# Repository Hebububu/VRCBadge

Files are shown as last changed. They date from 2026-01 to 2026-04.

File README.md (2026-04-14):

<div align="center">

# VRCBadge

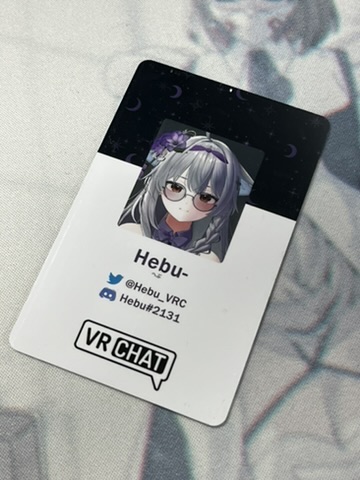
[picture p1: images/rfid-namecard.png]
RFID Namecard


I made RFID namecard before (for friends and myself)<br>
and you know, all VRC players change avatar quite often.

After making those namecards 3 times (dumb),<br>
I decided to make a digital badge for myself. (simple + fun toy project!)

It's gonna be a wearable digital badge powered by ESP32-S3<br>
Namecard looking UI (Yes, changeable image ofc)<br>
editable profile information (twitter, discord etc..), and future RFID door key emulation.

This project is inspired by Github Conference Badge video, posted by Wes Bos. [Ref Video](https://youtu.be/_jPm_zN95FE?si=vHjaHDR8lpRF7iKP)

### Working Prototype

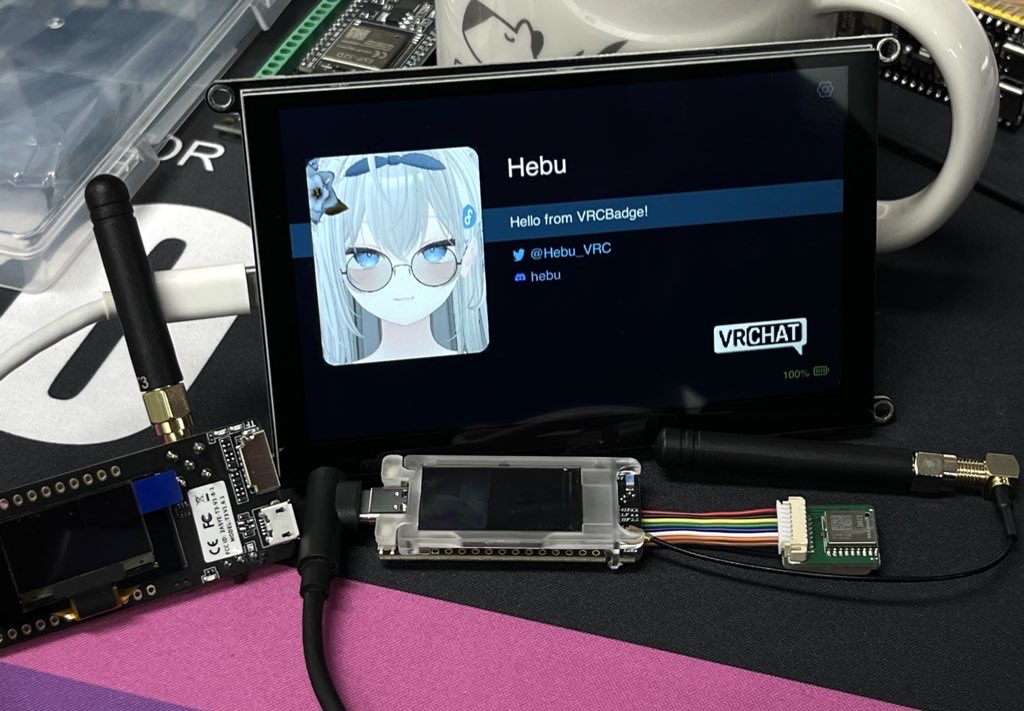
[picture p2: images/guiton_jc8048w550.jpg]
Badge running on Guition JC8048W550


Badge UI running on a Guition JC8048W550 dev board (ESP32-S3 + 4.8" RGB parallel LCD with capacitive touch). Built with [Slint](https://slint.dev).

### Enclosure (WIP)

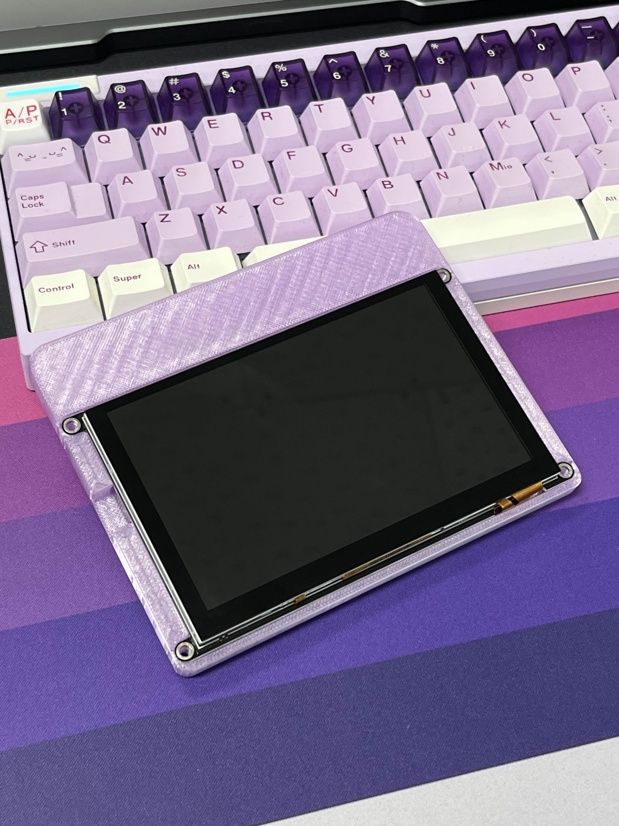
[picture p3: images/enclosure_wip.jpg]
Enclosure WIP

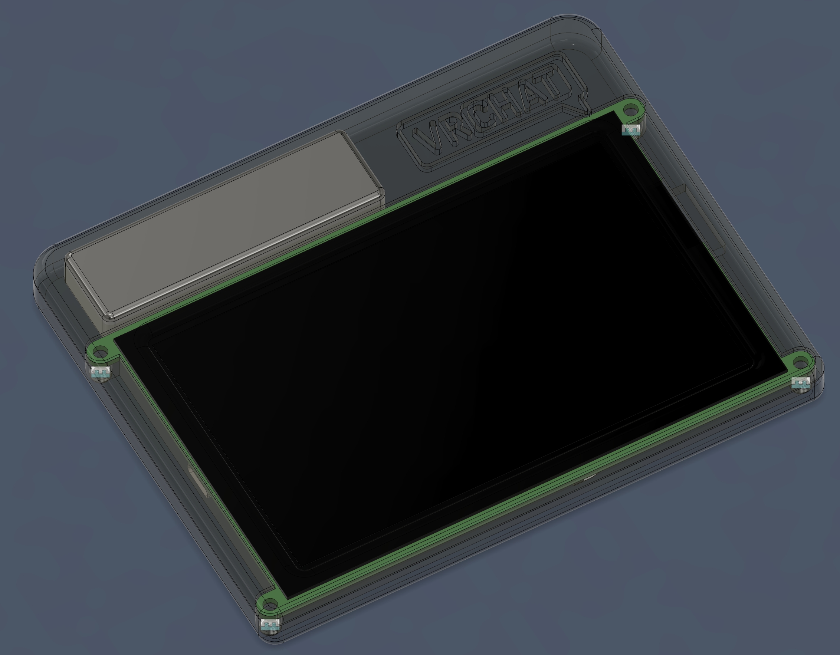
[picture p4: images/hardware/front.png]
Enclosure front render

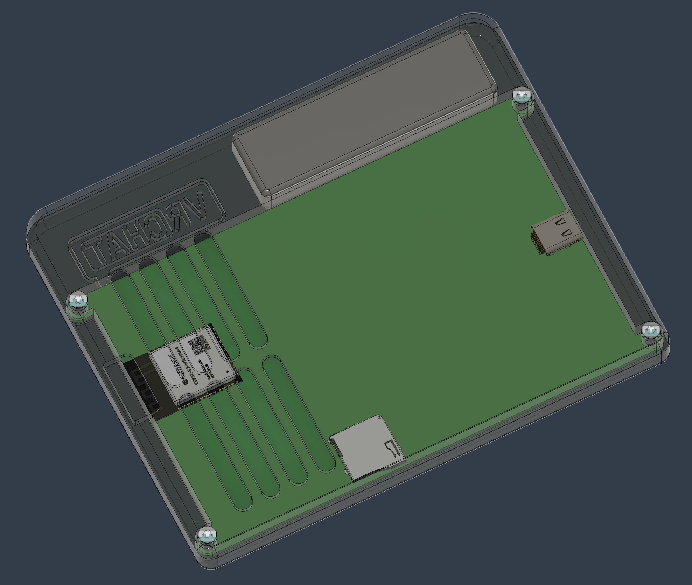
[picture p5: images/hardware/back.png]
Enclosure back render


Enclosure drawn with Autodesk Fusion 360.

### Schematic (Future)

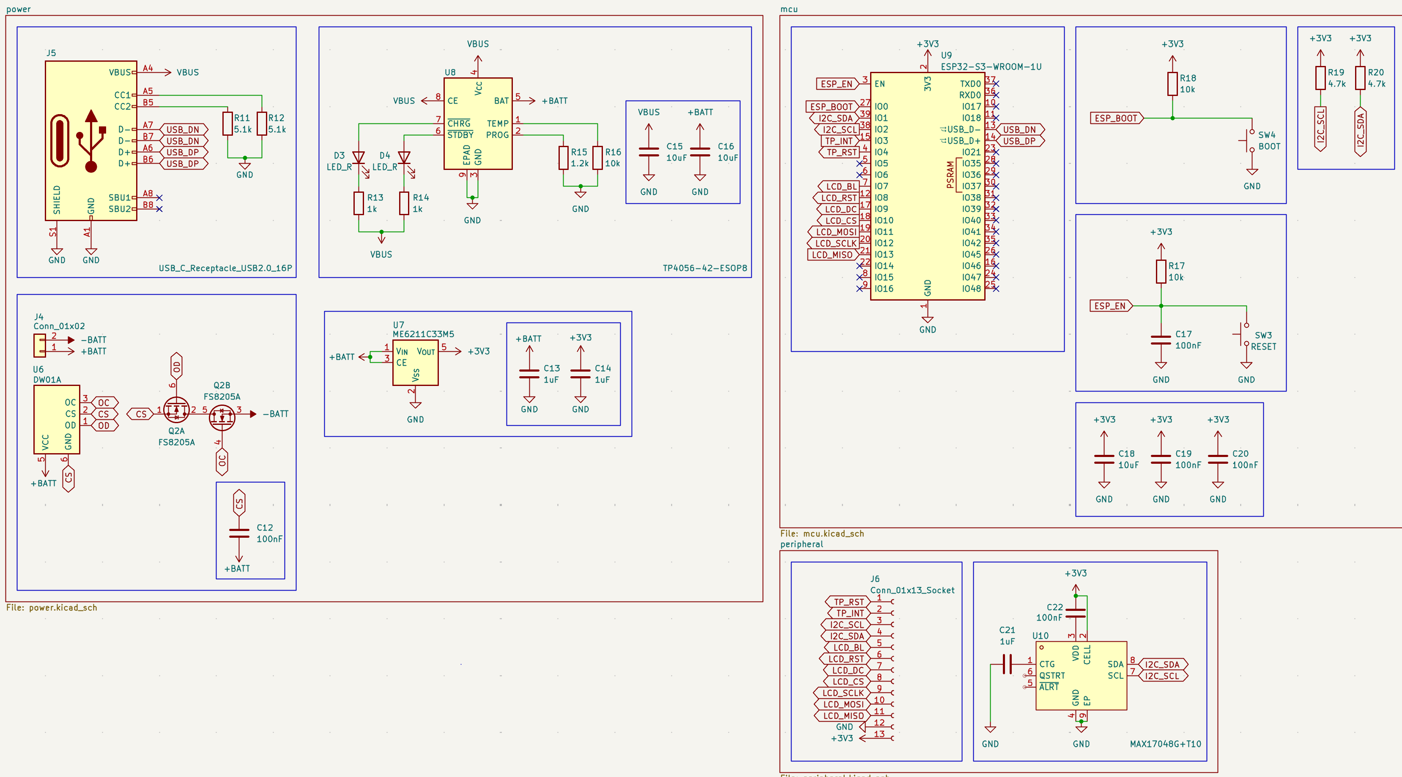
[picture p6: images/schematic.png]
Schematic


Custom 2-layer PCB designed for JLCPCB fabrication.
USB-C input with TP4056 LiPo charging, DW01A+FS8205A battery protection, and ME6211 3.3V LDO.
ESP32-S3-WROOM-1U drives a 3.5" SPI LCD with capacitive touch, while a MAX17048 fuel gauge tracks battery level over I2C.

</div>

## Documentation

See [/docs](./docs/README.md) for full documentation:

- [Hardware](./docs/hardware/) - ESP32-S3, custom PCB, display, BOM
- [Software](./docs/software/) - Architecture, API
- [RFID](./docs/rfid/) - Technical guide (future phase)

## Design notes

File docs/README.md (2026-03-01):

# Digital Conference Badge Documentation

A wearable digital badge with dynamic display, changeable avatar, and future RFID door key emulation.

## Documentation

### [Hardware](./hardware/)
- [Overview](./hardware/overview.md) - ESP32-S3 platform, Waveshare 3.5" display, PCB design, GPIO mapping, BOM
- [PCB Layout](./hardware/pcb.md) - Board dimensions, mounting holes, component placement

### [Software](./software/)
- [Architecture](./software/architecture.md) - System architecture, tech stack, data flow
- [API](./software/api.md) - HTTP endpoints documentation

### [RFID](./rfid/)
- [Technical Guide](./rfid/technical-guide.md) - RFID frequencies, reader vs emulator, Chameleon Tiny

## Resources

- [Slint Documentation](https://slint.dev/docs)
- [esp-idf-svc (Rust)](https://github.com/esp-rs/esp-idf-svc)
- [ESP32-S3 Datasheet](https://www.espressif.com/sites/default/files/documentation/esp32-s3_datasheet_en.pdf)
- [ESP-IDF Programming Guide](https://docs.espressif.com/projects/esp-idf/en/stable/esp32s3/)
- [esp-idf-hal (Rust)](https://github.com/esp-rs/esp-idf-hal)
- [Waveshare 3.5" RPi LCD (F)](https://www.waveshare.com/wiki/3.5inch_RPi_LCD_(F))
- [EasyEDA PCB Design](https://easyeda.com)
- [JLCPCB Fabrication](https://jlcpcb.com)
- [Chameleon Tiny Wiki](https://github.com/RfidResearchGroup/ChameleonUltra)

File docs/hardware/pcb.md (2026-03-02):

# PCB Layout

## Board Specification

- Width: 105mm
- Height: 80mm
- Corner radius: 2mm
- Mounting holes: 2mm diameter, one at each corner, 3.5mm from each edge

## Display Module Dimensions

Measurements from Waveshare 3.5" RPi LCD (F) specsheet.

### Panel Dimensions (front view, landscape orientation)

| Dimension | Value | Notes |
|---|---|---|
| Lens (outer) width | 92.44 +/- 0.20 mm | Glass/lens edge to edge |
| Lens (outer) height | 61.00 +/- 0.20 mm | Glass/lens edge to edge |
| Touch active area width | 73.84 +/- 0.10 mm | Usable touch/display region |
| Touch active area height | 49.36 +/- 0.10 mm | Usable touch/display region |
| Bezel left/right | 9.30 mm | Lens edge to active area |
| Bezel top/bottom | 5.82 mm | Lens edge to active area |

### PCB Dimensions (back view)

| Dimension | Value | Notes |
|---|---|---|
| PCB width | 56.00 mm | Back PCB behind the lens |
| PCB component area | 49.00 mm | Active component region |
| PCB left edge offset | 2.50 mm | From lens edge to PCB edge |
| PCB right edge offset | 3.50 mm | From lens edge to PCB edge |
| Connector row height | 3.46 mm | GH1.25 13-pin connector area |
| Mounting hole pattern | M2.50 | 4 holes on back PCB |
| Mounting hole spacing (vertical) | 27.73 mm | Between hole centers |
| Connector offset from edge | 2.31 mm | Horizontal offset |
| Component spacing | 2.55 mm | Between connector groups |

### Stack Height (side profile)

| Layer | Thickness | Notes |
|---|---|---|
| Touch panel + LCD | 3.95 mm | Glass + LCD panel combined |
| Air gap / clearance | 0.80 mm | Between LCD and back PCB |
| Back PCB + components | 6.60 mm | PCB with tallest component |
| **Total stack** | **~14.60 mm** | Front glass to back component tip |

### FPC Cable

| Dimension | Value | Notes |
|---|---|---|
| FPC exit direction | Bottom edge | In portrait orientation |
| FPC extension length | ~24.00 mm | Flexible cable extends from panel |
| FPC width | ~15.28 mm | Approximate |

## Orientation

All directions described as viewed from the front (LCD-facing) side.
Display is mounted in landscape orientation (92.44mm horizontal, 61.00mm vertical).

## Component Placement

- J6 (display connector): front side, left edge
- J5 (USB-C): back side, right edge, as close to ESP32 as possible
- J4 (Battery connector): back side, top-left edge
- U9 (ESP32-S3-WROOM-1U): antenna extends outside the frame
- SW3 (RESET) + SW4 (BOOT): back side, side by side, near ESP32, clickable from frame

## Clearance Notes

- Display stack is ~14.60mm total height -- back components must not exceed 6.60mm from PCB surface
- The display lens (92.44 x 61.00mm) is larger than the back PCB (56.00mm wide) -- the PCB board must extend beyond the lens width to accommodate mounting and connectors
- FPC cable routes from display bottom edge -- ensure clearance for the cable bend radius
- Board size (105 x 80mm) provides ~12.78mm margin on each side of the lens horizontally and ~9.50mm margin vertically for mounting holes and edge components

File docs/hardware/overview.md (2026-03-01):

# Hardware Overview

## Platform: ESP32-S3-WROOM-1U

### Module Specs

- **CPU:** Dual-core Xtensa LX7 @ 240MHz
- **SRAM:** 512KB
- **PSRAM:** 8MB Octal-SPI
- **Flash:** 16MB
- **Wireless:** WiFi 802.11 b/g/n + BLE 5.0
- **Antenna:** U.FL connector (external antenna)
- **Module size:** ~18x25mm
- **Unit cost:** ~$4-5

## Display: Waveshare 3.5" RPi LCD (F)

**Product:** [Waveshare 3.5inch RPi LCD (F)](https://www.waveshare.com/3.5inch-rpi-lcd-f.htm) (SKU: 30896)

| Spec | Value |
|---|---|
| Resolution | 320 x 480 (portrait default) |
| Display driver | ST7796S |
| Display interface | 4-wire SPI |
| Display panel | IPS |
| Viewing angle | 170° |
| Color depth | 262K RGB |
| Touch driver | GT911 |
| Touch interface | I2C |
| Touch type | 5-point capacitive |
| Touch panel | Toughened glass |
| Operating voltage | 3.3V - 5V (onboard regulator, powered from 3.3V rail in this design) |
| Logic level | 3.3V |
| Display area | 49.36 x 73.84 mm |
| Panel size | 61.00 x 92.44 mm |
| Refresh rate | 60Hz |
| Connector | GH1.25 13-pin cable or Pigo pin header |

### Pin Interface (13-pin)

| Pin # | Name | Description |
|---|---|---|
| 1 | TP_RST | Touch panel reset, low active |
| 2 | TP_INT | Touch panel interrupt |
| 3 | TP_SCL | Touch panel I2C clock |
| 4 | TP_SDA | Touch panel I2C data |
| 5 | LCD_BL | LCD backlight control |
| 6 | LCD_RST | LCD reset, low active |
| 7 | LCD_DC | LCD data/command select (high=data, low=command) |
| 8 | LCD_CS | LCD chip select, low active |
| 9 | SCLK | SPI clock |
| 10 | MOSI | SPI MOSI |
| 11 | MISO | SPI MISO |
| 12 | GND | Ground |
| 13 | VCC | Power input (3.3V - 5V) |

### Resources

- [ST7796S Datasheet](https://files.waveshare.com/wiki/common/ST7796S_Datasheet.pdf)
- [GT911 Datasheet](https://files.waveshare.com/wiki/common/GT911_Datasheet.pdf)
- [Display Schematic](https://files.waveshare.com/wiki/3.5inch%20RPi%20LCD%20(F)/3.5inch_RPi_LCD_(F).pdf)
- [Product Wiki](https://www.waveshare.com/wiki/3.5inch_RPi_LCD_(F))
- [ESP32-S3 Demo (Arduino)](https://files.waveshare.com/wiki/3.5inch_RPi_LCD_F/3inch5_RPI_LCD_F_ESP32S3.zip)

## PCB Design

### Component Summary

| Component | Part | Notes |
|---|---|---|
| MCU | ESP32-S3-WROOM-1U | Soldered directly to PCB, U.FL antenna |
| Display | Waveshare 3.5" RPi LCD (F) | Connected via GH1.25 13-pin cable |
| Charger | TP4056 (ESOP-8) | LiPo charging from USB-C 5V |
| Battery protection | DW01A + FS8205A | Over-discharge/over-current protection |
| LDO | ME6211C33M5 | 3.3V regulation from LiPo (3.0-4.2V), 500mA |
| Fuel gauge | MAX17048G+T10 | Battery voltage/percentage via I2C |
| Connector | USB-C (16-pin) | Charging + programming (built-in USB-JTAG) |
| Buttons | 2x tactile switch | BOOT (IO0) + RESET (EN) |
| LEDs | 2x LED (D1, D2) | Charge (CHG) and standby (STDBY) indicators |
| Battery | 3.7V 3000mAh LiPo pouch | |

### Power Path

```
USB-C 5V --> TP4056 --> LiPo 3.7V --> DW01A/FS8205A --> ME6211 --> 3.3V rail
                                                                      |
                                                                      +-- ESP32-S3
                                                                      +-- ST7796S display
                                                                      +-- GT911 touch
                                                                      +-- MAX17048
```

The ME6211C33M5 is a low-dropout regulator with 500mA output. Dropout voltage is ~100mV at light load, so it works down to ~3.4V LiPo voltage. Below that, the battery is near empty anyway (3.0V cutoff from DW01A).

**Current budget note:** ESP32-S3 peak draw during WiFi TX is ~500mA. ST7796S backlight adds ~40-80mA, GT911 ~10mA, MAX17048 ~50uA. Combined peak may reach or exceed 500mA — verify during prototyping. If insufficient, consider upgrading to a higher-current regulator.

### GPIO Pin Mapping

| Function | ESP32-S3 Pin | Interface | Notes |
|---|---|---|---|
| BOOT | IO0 | GPIO | Boot mode select (SW1) |
| I2C SDA | IO1 | I2C | Shared: GT911 touch + MAX17048 |
| I2C SCL | IO2 | I2C | Shared: GT911 touch + MAX17048 |
| Touch INT | IO3 | GPIO (input) | Interrupt, active low |
| Touch RST | IO4 | GPIO | Reset, low active |
| Display BL | IO7 | PWM | Backlight brightness control |
| Display RST | IO8 | GPIO | Reset, low active |
| Display DC | IO9 | GPIO | Data/command select |
| Display CS | IO10 | SPI | Chip select, low active |
| Display MOSI | IO11 | SPI | SPI data out |
| Display SCLK | IO12 | SPI | SPI clock |
| Display MISO | IO13 | SPI | Wired but unused (SPI is write-only) |
| USB D- | USB_D- | USB-JTAG | Built-in USB (pin 13) |
| USB D+ | USB_D+ | USB-JTAG | Built-in USB (pin 14) |
| EN | EN | — | R10 10k pull-up + C9 100nF RC + SW2 RESET |

**I2C bus sharing:** The GT911 touch controller (default address: 0x5D) and MAX17048 fuel gauge (address: 0x36) share the same I2C bus on IO1/IO2. No address conflict. Pull-ups: R8 4.7k (SCL), R9 4.7k (SDA).

**Unused pins:** IO5, IO6, IO14-IO18, IO21, IO35-IO48, TXD0, RXD0 are marked no-connect.

## BOM Estimate

| Category | Item | Cost |
|---|---|---|
| MCU | ESP32-S3-WROOM-1U | $4-5 |
| Display | Waveshare 3.5" RPi LCD (F) | ~$20 |
| Battery | 3.7V 3000mAh LiPo pouch | $5-8 |
| Charger IC | TP4056 (ESOP-8) | $0.20 |
| Protection | DW01A + FS8205A | $0.30 |
| LDO | ME6211C33M5 | $0.20 |
| Fuel gauge | MAX17048G+T10 | $2-3 |
| Connector | USB-C (16-pin) | $0.30 |
| Buttons | 2x tactile switch (BOOT + RESET) | $0.20 |
| LEDs | 2x LED + resistors (CHG/STDBY) | $0.20 |
| Passives | Resistors, capacitors, etc. | $1-2 |
| PCB fab | JLCPCB 2-layer + SMT assembly | $10-30 |
| **Total** | | **~$45-70** |

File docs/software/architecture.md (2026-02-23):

# Software Architecture

## System Overview

```mermaid
graph TB
    subgraph Badge["Badge Software (ESP32-S3)"]
        UI["Slint UI"]
        API["esp-idf-svc HTTP Server"]
        Storage["Flash Storage (NVS + SPIFFS)"]
        Monitor["System Monitor"]
    end

    subgraph Peripherals
        Display["ST7796S Display (SPI)"]
        Touch["GT911 Touch (I2C)"]
        Battery["MAX17048 Fuel Gauge (I2C)"]
        RFID["Chameleon Tiny (UART, future)"]
    end

    Phone["Phone / Browser"] -->|"WiFi HTTP"| API
    API -->|"avatar upload"| Storage
    API -->|"profile update"| UI
    Storage -->|"load avatar"| UI
    UI -->|"framebuffer + DMA"| Display
    Touch -->|"touch events"| UI
    Monitor -->|"battery %"| UI
    Battery -->|"I2C read"| Monitor
    RFID -.->|"UART (future)"| API
```

## Tech Stack

```
Slint (UI framework)           — software renderer, full framebuffer with dirty-rect updates
esp-idf-svc (HTTP, WiFi, NVS) — synchronous HTTP server, WiFi AP, non-volatile storage
esp-idf-hal (GPIO/SPI/I2C)    — hardware abstraction (SPI display, I2C touch, PWM backlight)
SPIFFS                         — flash-based filesystem for images (mounted at /storage)
```

## Slint on MCU

From the Slint embedded documentation, the key configuration:

**Cargo features needed (default-features = false):**
- `compat-1-2`
- `renderer-software`
- `unsafe-single-threaded`
- `libm`

**Rendering strategy — full framebuffer with dirty-rect DMA:**
- Full 480x320 RGB565 framebuffer (300KB) allocated in PSRAM via `heap_caps_malloc`
- Slint's dirty tracking identifies changed rectangles (typically 3-7 per frame)
- Only dirty rectangles are sent to the display over SPI
- 4KB DMA buffer allocated in internal SRAM for SPI transfers
- `mipidsi` batches pixels into the SPI buffer automatically
- Build script must set `EmbedResourcesKind::EmbedForSoftwareRenderer`

## Data Flow

### Avatar Upload

```
Phone (browser) -> resize to 150x150, strip alpha (RGBA -> RGB)
  -> POST /api/avatar (raw RGB888, 67,500 bytes) -> HTTP handler
  -> store in pending slot -> main loop picks up
  -> save to SPIFFS (/storage/avatar.rgb) + update Slint UI
```

### Profile Update

```
Phone -> POST /api/profile (JSON, max 4KB) -> HTTP handler
  -> store in pending slot -> main loop picks up
  -> save to NVS (namespace "badge", key "profile")
  -> update Slint UI text + colors
```

### Battery Monitoring (planned)

```
MAX17048 (I2C, addr 0x36) -> periodic read -> System Monitor
  -> update Slint UI battery indicator
  (currently hardcoded to 100% — driver not yet implemented)
```

### Touch Input

```
Main loop polls GT911 (I2C) -> read touch coordinates
  -> coordinate transform (portrait GT911 -> landscape display)
  -> dispatch Slint events (Pressed/Moved/Released/Exited)
```

### Captive Portal

```
DNS server (UDP :53, background thread, 4KB stack)
  -> all A-record queries resolve to AP IP (TTL 60s)

HTTP captive portal detection:
  /generate_204          (Android / Chrome OS)
  /hotspot-detect.html   (iOS / macOS)
  /connecttest.txt       (Windows)
  /canonical.html        (Firefox)
  + wildcard /*          (fallback)
  -> 302 redirect to http://<AP_IP>/  -> serves embedded SPA
```

### Backlight Control

```
Settings page slider (10-100%) -> on_brightness_changed callback
  -> LEDC PWM on GPIO 7 (25kHz, 8-bit resolution)
  -> debounced (2% threshold to avoid flicker)
  -> starts at 50% brightness on boot
```

## Storage Layout

```
16MB Flash:
  ~4MB  - Firmware (application binary)
  ~12MB - SPIFFS partition (mounted at /storage)
           +-- avatar.rgb      (150x150 raw RGB888, 67.5KB)
           +-- background.rgb  (480x320 raw RGB888, 450KB)

NVS (non-volatile storage, separate partition):
  namespace "badge":
    key "profile" -> JSON string (display name, tagline, socials, colors)
```

For `std` mode, esp-idf's VFS layer maps the SPIFFS partition to `/storage/`, so standard `std::fs` calls work transparently. NVS is accessed via `esp-idf-svc`'s `EspNvs` API.

## API Endpoints

See [API documentation](./api.md) for full endpoint specifications.

| Method | Endpoint | Description | Status |
|---|---|---|---|
| GET | /api/health | Simple healthcheck | Implemented |
| GET | /api/profile | Get current profile as JSON | Implemented |
| POST | /api/profile | Update name, tagline, socials, colors | Implemented |
| POST | /api/avatar | Upload avatar image (raw RGB888) | Implemented |
| POST | /api/background | Upload background image (raw RGB888) | Implemented |
| DELETE | /api/background | Clear background (revert to solid color) | Implemented |
| GET | /api/status | Battery %, WiFi strength, uptime | Planned |
| GET | /api/rfid/slots | List stored cards | Future |
| POST | /api/rfid/slot/:id | Activate card slot | Future |

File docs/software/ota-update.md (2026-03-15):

# OTA Firmware Update via GitHub Releases

## Overview

When the badge connects to WiFi (STA mode), it checks GitHub for a newer
firmware release. If one exists, it shows a notification and an "Install
Update" button on the About page. The user taps to download and flash the
new firmware via ESP-IDF's OTA mechanism, then the device reboots.

## Decisions

| Decision | Answer |
|---|---|
| GitHub repo | `Hebububu/VRCBadge` |
| API endpoint | `https://api.github.com/repos/Hebububu/VRCBadge/releases/latest` |
| Tag format | `v0.1.0` (with `v` prefix) |
| Asset filename | `firmware.bin` |
| Version comparison | Strip `v` prefix, compare strings (no semver lib) |
| JSON parsing | Simple string search (no serde_json) |
| Update trigger | Auto-check on STA connect + manual button on About  |
| Update flow | User taps "Install Update" -> background thread -> reboot |
| Progress updates | `Arc<Mutex<>>` struct polled by main loop |
| Rollback protection | `mark_valid()` at boot + ESP-IDF automatic rollback  |
| Partition layout | ota_0 (3 MB) + ota_1 (3 MB) + SPIFFS (~10 MB) |

## Architecture

```mermaid
flowchart TD
    subgraph GitHub
        R[GitHub Release v0.2.0]
        R --> A[firmware.bin asset]
    end

    subgraph "ESP32-S3 (Badge)"
        subgraph "ota.rs"
            CU[check_update]
            PU[perform_update]
            MV[mark_valid]
        end

        subgraph "Main Loop"
            AC[Auto-check on STA connect]
            POLL[Poll OtaProgress every ~2s]
            BOOT[mark_valid on boot]
        end

        subgraph "UI (About Page)"
            BTN1[Check for Updates button]
            BTN2[Install Update button]
            PROG[Progress bar]
            STATUS[Status text]
        end

        subgraph "Background Thread"
            DL[Download firmware.bin]
            OTA[EspOtaUpdate::write chunks]
            DONE[EspOtaUpdate::complete]
            REBOOT[Restart]
        end
    end

    AC -->|on STA connect| CU
    BTN1 -->|user tap| CU
    CU -->|HTTPS GET /releases/latest| R
    CU -->|parse JSON| STATUS
    BTN2 -->|user tap| PU
    PU --> DL
    DL -->|HTTPS GET firmware.bin| A
    DL --> OTA
    OTA -->|progress_cb| POLL
    POLL --> PROG
    OTA --> DONE
    DONE --> REBOOT
    REBOOT -->|after reboot| BOOT
    BOOT --> MV
```

## Update Flow (Sequence)

```mermaid
sequenceDiagram
    participant User
    participant UI as Slint UI
    participant Main as Main Loop
    participant OTA as ota.rs
    participant GH as GitHub API
    participant ESP as ESP-IDF OTA

    Note over Main: Boot
    Main->>ESP: mark_valid()
    Main->>Main: WiFi STA connects

    Main->>OTA: check_update()
    OTA->>GH: GET /repos/Hebububu/VRCBadge/releases/latest
    GH-->>OTA: JSON (tag_name, assets[].browser_download_url)
    OTA->>OTA: Compare tag_name vs CARGO_PKG_VERSION
    OTA-->>Main: Some(UpdateInfo { version, download_url })
    Main->>UI: set update-available, update-version
    UI->>UI: Show toast "Update available: v0.2.0"

    User->>UI: Tap "Install Update"
    UI->>Main: install-update callback
    Main->>Main: std::thread::spawn

    Note over Main: Background Thread
    Main->>OTA: perform_update(url, progress_cb)
    OTA->>GH: GET firmware.bin (follows redirects)
    loop Stream chunks
        GH-->>OTA: chunk (4 KB)
        OTA->>ESP: EspOtaUpdate::write(chunk)
        OTA->>Main: progress_cb(downloaded, total)
        Main->>UI: set update-progress
    end
    OTA->>ESP: EspOtaUpdate::complete()
    OTA->>ESP: esp_restart()
```

## Partition Table

### Current (factory, no OTA)

```mermaid
block-beta
    columns 1
    block:flash["16 MB Flash"]:1
        BL["Bootloader\n0x0000 - 0x9000"]
        NVS["nvs (24 KB)\n0x9000 - 0xF000"]
        PHY["phy_init (4 KB)\n0xF000 - 0x10000"]
        FAC["factory (3.9 MB)\n0x10000 - 0x400000"]
        STO["storage / SPIFFS (12 MB)\n0x400000 - 0x1000000"]
    end

    style BL fill:#555,color:#fff
    style NVS fill:#4a6fa5,color:#fff
    style PHY fill:#4a6fa5,color:#fff
    style FAC fill:#2d6a4f,color:#fff
    style STO fill:#7b2d8b,color:#fff
```

### New (OTA-capable)

```mermaid
block-beta
    columns 1
    block:flash["16 MB Flash"]:1
        BL["Bootloader\n0x0000 - 0x9000"]
        NVS["nvs (24 KB)\n0x9000 - 0xF000"]
        OD["otadata (8 KB)\n0xF000 - 0x11000"]
        PHY["phy_init (4 KB)\n0x11000 - 0x20000"]
        OTA0["ota_0 (3 MB)\n0x20000 - 0x320000"]
        OTA1["ota_1 (3 MB)\n0x320000 - 0x620000"]
        STO["storage / SPIFFS (~10 MB)\n0x620000 - 0x1000000"]
    end

    style BL fill:#555,color:#fff
    style NVS fill:#4a6fa5,color:#fff
    style OD fill:#b5651d,color:#fff
    style PHY fill:#4a6fa5,color:#fff
    style OTA0 fill:#2d6a4f,color:#fff
    style OTA1 fill:#1b4332,color:#fff
    style STO fill:#7b2d8b,color:#fff
```

```csv
# Name,     Type, SubType, Offset,   Size
nvs,        data, nvs,     0x9000,   0x6000
otadata,    data, ota,     0xF000,   0x2000
phy_init,   data, phy,     0x11000,  0x1000
ota_0,      app,  ota_0,   0x20000,  0x300000
ota_1,      app,  ota_1,   0x320000, 0x300000
storage,    data, spiffs,  0x620000, 0x9E0000
```

**Breaking change**: existing devices require full re-flash. SPIFFS data
(avatar, background) will be lost.

## ota.rs API

```rust
pub struct UpdateInfo {
    pub version: String,
    pub download_url: String,
}

/// Check GitHub for a newer release.
pub fn check_update() -> anyhow::Result<Option<UpdateInfo>>

/// Download and flash firmware via OTA.
/// Calls progress_cb(downloaded_bytes, total_bytes) during download.
pub fn perform_update(
    url: &str,
    progress_cb: impl FnMut(usize, usize),
) -> anyhow::Result<()>

/// Mark running firmware as valid (prevents rollback on next reboot).
pub fn mark_valid() -> anyhow::Result<()>
```

## UI Changes (About Page)

Below the existing four info rows (~220px free space):

```
| ---------------------------------------- |
| SOFTWARE UPDATE                          |  Section header (14px, #555580)
| ---------------------------------------- |
| Status     Up to date / v0.2.0 available |  Dynamic status row
| ---------------------------------------- |
| [Check for Updates]    [Install Update]  |  Buttons (blue / green)
| ---------------------------------------- |
| [===============>          ] 45%         |  Progress bar (during OTA)
| ---------------------------------------- |
```

### New BadgeUI properties

| Property | Type | Default | Description |
|---|---|---|---|
| `update-available` | bool | false | Whether a newer version exists |
| `update-version` | string | "" | Remote version (e.g., "0.2.0") |
| `update-status` | string | "" | Human-readable status text |
| `update-progress`  | float  | 0.0 | Download progress (0.0 to 1.0) |

### New BadgeUI callbacks

| Callback | Description |
|---|---|
| `check-update()` | Triggers `ota::check_update()` |
| `install-update()` | Triggers `ota::perform_update()` on thread |

## Threading

`perform_update()` blocks for 30-60 seconds. Runs on a separate
`std::thread`. Progress shared via `Arc<Mutex<OtaProgress>>` polled
by the main loop every ~2 seconds.

```rust
enum OtaState {
    Idle,
    Checking,
    UpdateAvailable,
    Downloading,
    Installing,
    Done,
    Failed(String),
}

struct OtaProgress {
    state: OtaState,
    downloaded: usize,
    total: usize,
}
```

## HTTPS / TLS Notes

- GitHub API requires `User-Agent` header (rejects without it)
- Asset downloads redirect through `objects.githubusercontent.com` ->
  need `FollowRedirectsPolicy::FollowAll`
- Certificate bundle (~60 KB flash) for TLS verification
- ~40-50 KB heap per TLS connection; one connection at a time
- Set `crt_bundle_attach: Some(esp_crt_bundle_attach)` on HTTP client config

### sdkconfig.defaults additions

```
CONFIG_MBEDTLS_CERTIFICATE_BUNDLE=y
CONFIG_MBEDTLS_CERTIFICATE_BUNDLE_DEFAULT_FULL=y
CONFIG_BOOTLOADER_APP_ROLLBACK_ENABLE=y
```

## Risks & Mitigations

| Risk | Mitigation |
|---|---|
| JSON parsing without serde | Simple string search for tag_name + download URL |
| TLS memory (~50 KB) | One connection at a time; close after each request |
| Download interrupted mid-OTA | EspOtaUpdate validates on complete(); old FW stays  |
| New firmware crashes | mark_valid() + ESP-IDF automatic rollback |
| GitHub rate limit (60 req/hr) | Check once per STA connect + manual button only |
| Partition table change | Full re-flash required (accepted) |

## Stages

### Stage 1: Partition table + OTA backend
**Goal**: OTA-capable partition layout, `ota.rs` module with check/update/mark_valid
**Files**: `partitions.csv`, `sdkconfig.defaults`, `firmware/src/ota.rs`, `firmware/src/main.rs`
**Success Criteria**: Firmware builds and boots with new partition table; `mark_valid()` succeeds at startup
**Tests**: Boot log shows ota_0 partition; `check_update()` returns result from GitHub API
**Status**: Not started

### Stage 2: UI + wiring
**Goal**: About page update section, callbacks wired, auto-check on STA connect
**Files**: `ui/badge.slint`, `firmware/src/main.rs`
**Success Criteria**: "Check for Updates" calls GitHub API; "Install Update" downloads and flashes OTA
**Tests**: Create a test GitHub release with firmware.bin; verify full update cycle with reboot
**Status**: Not started

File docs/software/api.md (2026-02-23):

# API Endpoints

All endpoints are served by the esp-idf-svc HTTP server on port 80 over the badge's WiFi AP.

## Implemented Endpoints

| Method | Endpoint | Description |
| --- | --- | --- |
| GET | /api/health | Simple healthcheck (returns `OK`) |
| GET | /api/profile | Get current profile as JSON |
| POST | /api/profile | Update profile from JSON |
| POST | /api/avatar | Upload avatar image |
| POST | /api/background | Upload background image |
| DELETE | /api/background | Clear background (revert to solid color) |

### GET /api/health

Returns `OK` with status 200. Used to verify the server is running.

### GET /api/profile

Returns the current profile as JSON:

```json
{
  "display_name": "Hebu",
  "tagline": "Hello from VRCBadge!",
  "twitter_handle": "@Hebu_VRC",
  "discord_handle": "hebu",
  "background_color": "#1a1a2e",
  "tagline_color": "#e0e8f0",
  "tagline_background_color": "#1b4f72"
}
```

### POST /api/profile

Update the profile. Request body is JSON (max 4KB), same schema as the GET response. The main loop picks up the update and saves to NVS within ~2 seconds.

### POST /api/avatar

Upload a new avatar image. The request body must be **exactly 67,500 bytes** of raw RGB888 pixel data (150 x 150 x 3 bytes). No headers or encoding — just raw bytes with `Content-Length: 67500`.

The browser SPA handles resizing and RGBA-to-RGB conversion client-side before upload.

### POST /api/background

Upload a new background image. The request body must be **exactly 460,800 bytes** of raw RGB888 pixel data (480 x 320 x 3 bytes). Same raw format as avatar.

### DELETE /api/background

Clears the background image and reverts the badge display to its solid background color. Deletes the saved image from SPIFFS.

## Planned Endpoints

| Method | Endpoint | Description |
| --- | --- | --- |
| GET | /api/status | System status (battery %, uptime, WiFi info) |

## Future Endpoints (RFID)

| Method | Endpoint | Description |
| --- | --- | --- |
| GET | /api/rfid/slots | List stored cards |
| POST | /api/rfid/slot/:id | Activate card slot |

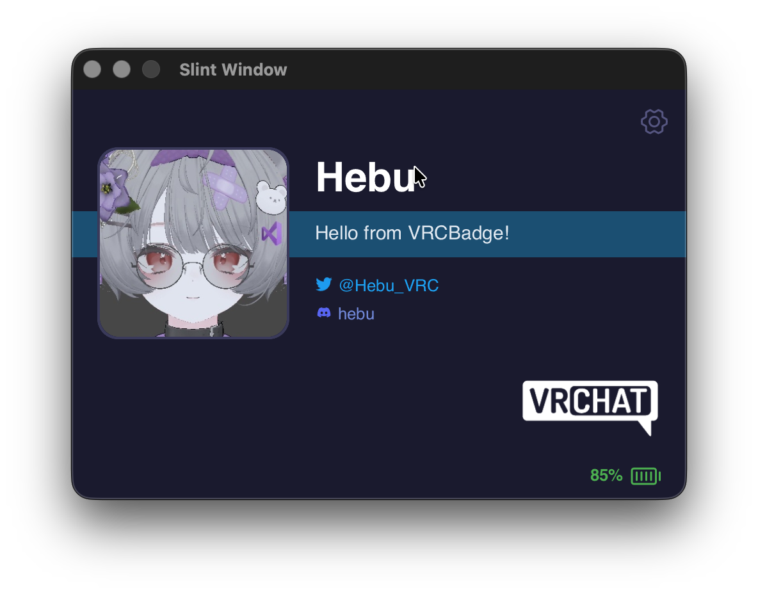
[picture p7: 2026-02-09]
images/etc/slint_preview.png

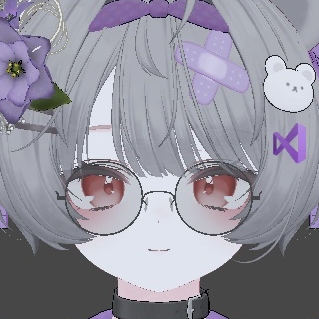
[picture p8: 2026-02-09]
images/profile/sample.png

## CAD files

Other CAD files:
fusion360/enclosure.f3d

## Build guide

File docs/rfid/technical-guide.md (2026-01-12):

# RFID Technical Guide (Future Phase)

## How RFID Door Locks Work

```mermaid
sequenceDiagram
    participant Reader as Reader (Door)
    participant Card as Card (Key)

    Reader->>Card: 1. Emits RF field )))
    Note over Card: 2. Powered passively by field
    Card->>Reader: 3. Transmits UID/data
    Note over Reader: 4. Checks whitelist
    Reader->>Reader: 5. Access granted/denied
```

## Two Frequencies

| Frequency | Names | Use | Security |
| --- | --- | --- | --- |
| 125 kHz | EM4100, HID Prox | Older buildings | Low (UID only) |
| 13.56 MHz | MIFARE, NFC | Modern systems  | Varies |

## Reader vs Emulator

| Type | Function | Badge Use |
| --- | --- | --- |
| Reader (RC522, PN532) | Reads/writes cards | Cannot act as card |
| Emulator (Chameleon, Proxmark) | Pretends to BE a card | Required |

## Recommended: Chameleon Tiny/Ultra

- Supports both frequencies
- USB serial interface
- Multiple card slots
- Controllable from Rust via `serialport` crate

## Identify Your Door Lock First

```
Method 1: Check card for "HID" (125kHz) or "MIFARE" (13.56MHz)
Method 2: Try scanning with Android NFC (if reads = 13.56MHz)
Method 3: Ask building management
```

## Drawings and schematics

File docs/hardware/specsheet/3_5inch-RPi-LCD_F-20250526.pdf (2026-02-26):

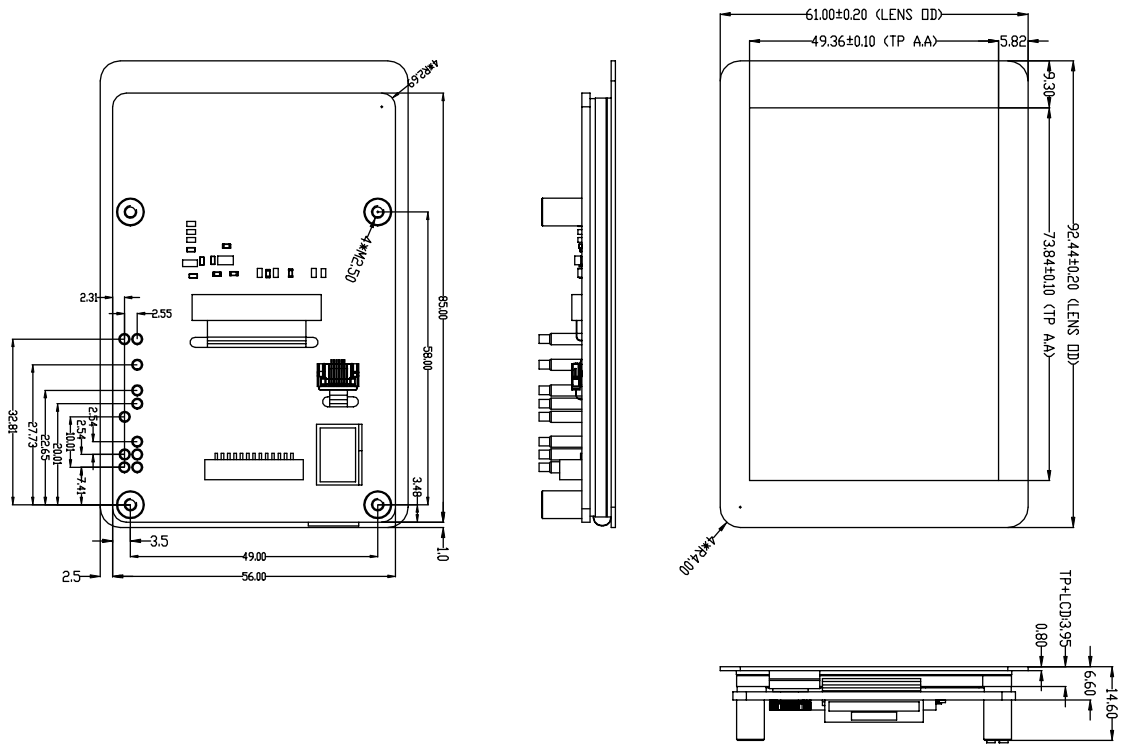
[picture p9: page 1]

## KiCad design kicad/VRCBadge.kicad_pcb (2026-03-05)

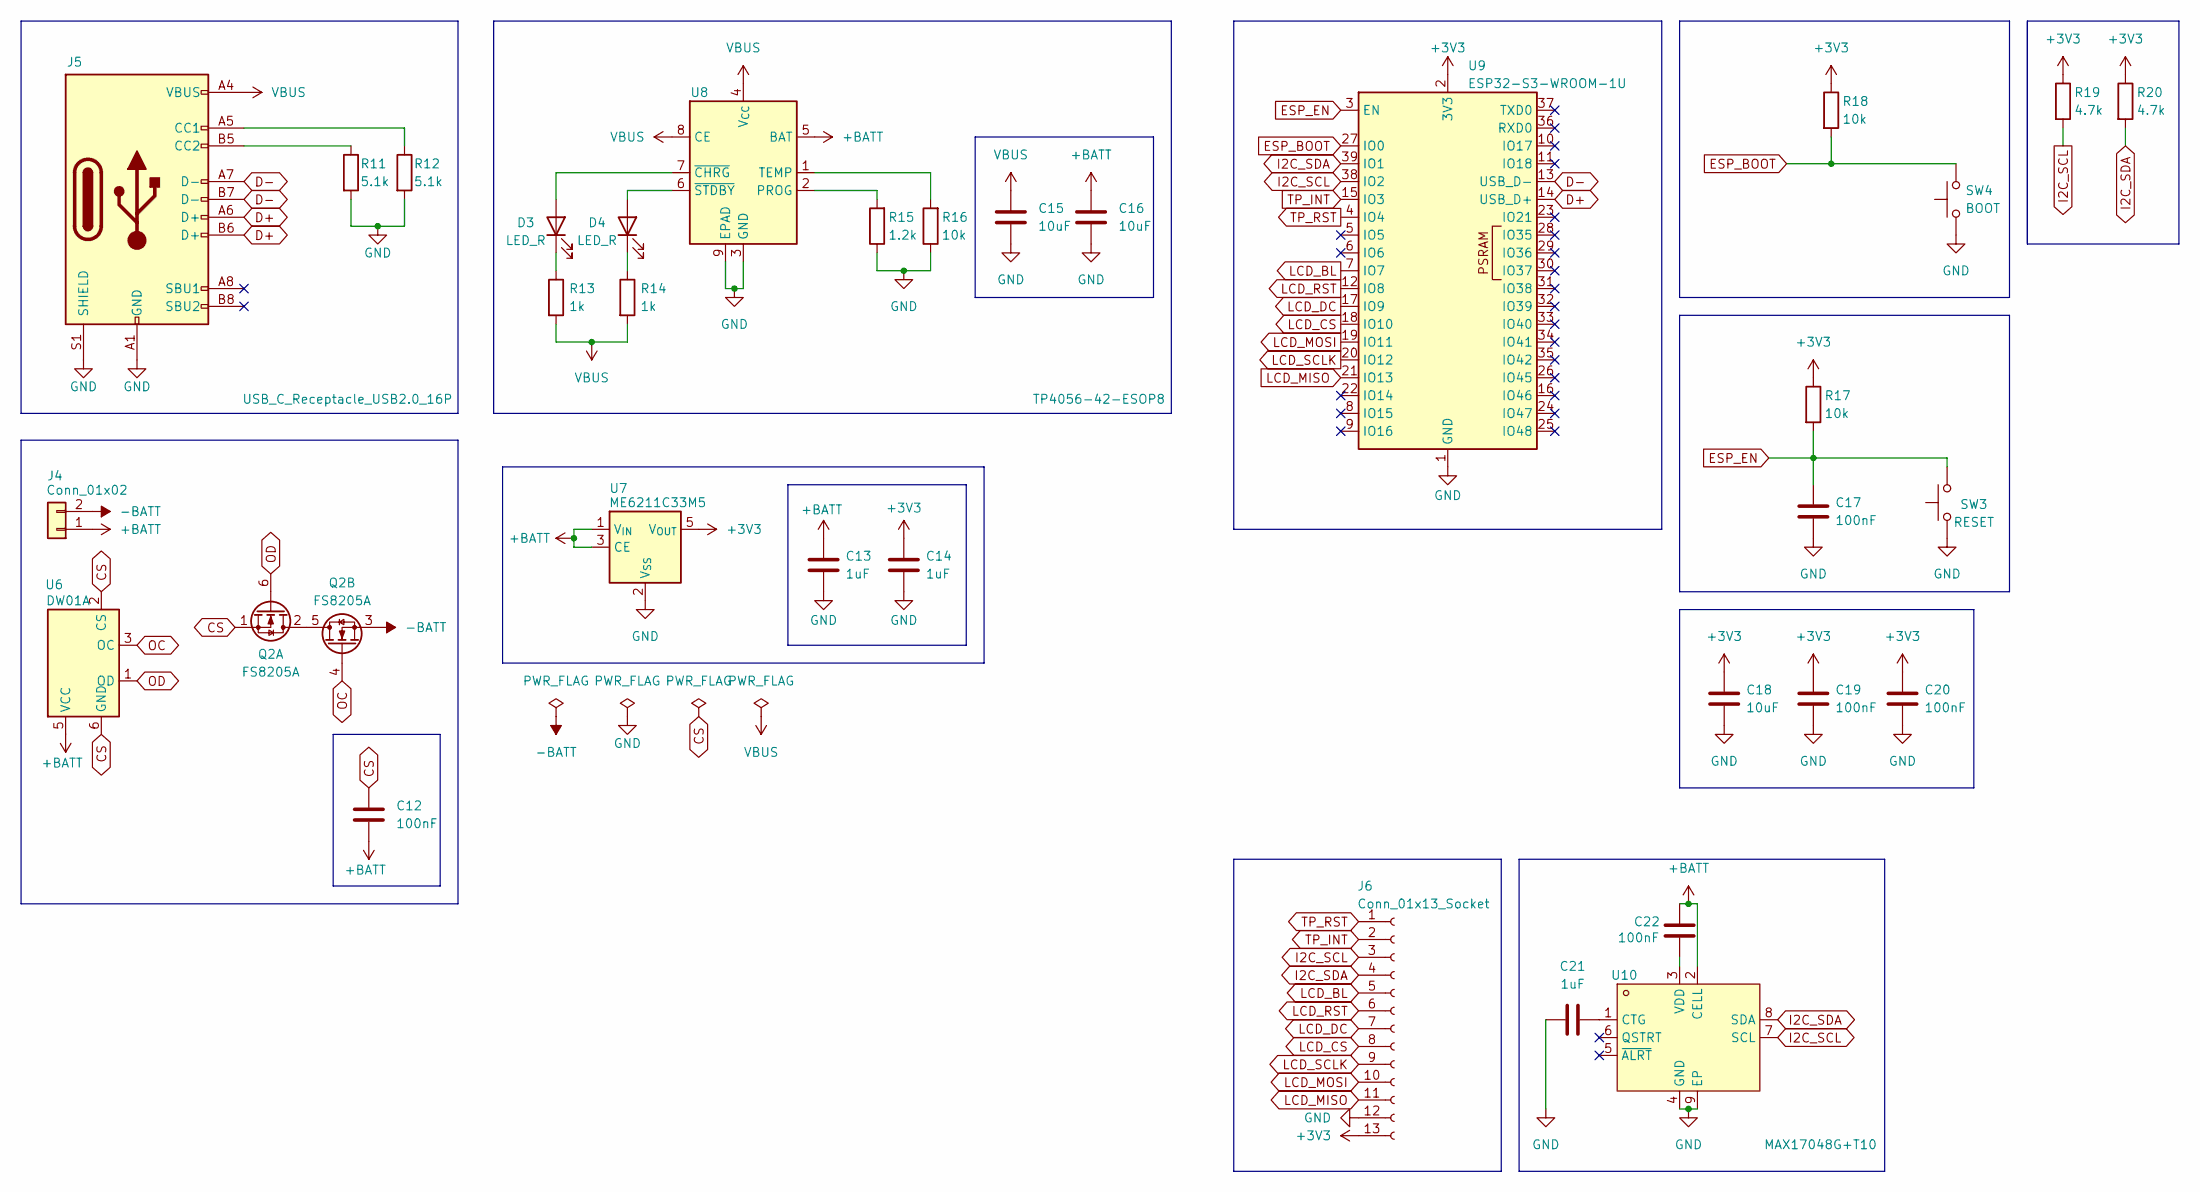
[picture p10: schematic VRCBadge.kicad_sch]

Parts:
C12, C17, C19, C20, C22: 100nF; C_0402_1005Metric
C13, C14, C21: 1uF; C_0402_1005Metric
C15, C16, C18: 10uF; C_0402_1005Metric
D3, D4: LED_R; LED_0402_1005Metric
J4: Conn_01x02; JST_PH_S2B-PH-K_1x02_P2.00mm_Horizontal
J5: USB_C_Receptacle_USB2.0_16P; USB_C_Receptacle_HRO_TYPE-C-31-M-12
J6: Conn_01x13_Socket; JST_GH_SM13B-GHS-TB_1x13-1MP_P1.25mm_Horizontal
Q2: FS8205A; SOT-23-6; LCSC Part C32254
R11, R12: 5.1k; R_0402_1005Metric
R13, R14: 1k; R_0402_1005Metric
R15: 1.2k; R_0402_1005Metric
R16, R17, R18: 10k; R_0402_1005Metric
R19, R20: 4.7k; R_0402_1005Metric
SW3: RESET; SW_SPST_TL3342
SW4: BOOT; SW_SPST_TL3342
U6: DW01A; SOT-23-6
U7: ME6211C33M5; SOT-23-5
U8: TP4056-42-ESOP8; SOIC-8-1EP_3.9x4.9mm_P1.27mm_EP2.41x3.3mm_ThermalVias
U9: ESP32-S3-WROOM-1U
U10: MAX17048G+T10; TDFN-8_L2.0-W2.0-P0.50-BL-EP1.2; LCSC Part C2682616

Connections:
+3V3: C14.1, C18.1, C19.1, C20.1, J6.13, R17.1, R18.1, R19.1, R20.1, U7.5 (V_{OUT}), U9.2 (3V3)
+BATT: C12.2, C13.1, C16.1, C22.1, J4.1, U6.5 (VCC), U7.1 (V_{IN}), U7.3 (CE), U8.5 (BAT), U10.2 (CELL)
-BATT: J4.2, Q2.3 (S)
CS: C12.1, Q2.1 (S), U6.2 (CS), U6.6 (GND)
D+: J5.A6 (D+), J5.B6 (D+), U9.14 (USB_D+)
D-: J5.A7 (D-), J5.B7 (D-), U9.13 (USB_D-)
ESP_BOOT: R18.2, SW4.2, U9.27 (IO0)
ESP_EN: C17.1, R17.2, SW3.1, U9.3 (EN)
GND: C13.2, C14.2, C15.2, C16.2, C17.2, C18.2, C19.2, C20.2, C21.2, J5.A1 (GND), J5.A12 (GND), J5.B1 (GND), J5.B12 (GND), J5.S1 (SHIELD), J6.12, R11.2, R12.2, R15.1, R16.1, SW3.2, SW4.1, U7.2 (V_{SS}), U8.3 (GND), U8.9 (EPAD), U9.1 (GND), U9.40 (GND), U9.41 (GND), U10.4 (GND), U10.9 (EP)
I2C_SCL: J6.3, R19.2, U9.38 (IO2), U10.7 (SCL)
I2C_SDA: J6.4, R20.2, U9.39 (IO1), U10.8 (SDA)
LCD_BL: J6.5, U9.7 (IO7)
LCD_CS: J6.8, U9.18 (IO10)
LCD_DC: J6.7, U9.17 (IO9)
LCD_MISO: J6.11, U9.21 (IO13)
LCD_MOSI: J6.10, U9.19 (IO11)
LCD_RST: J6.6, U9.12 (IO8)
LCD_SCLK: J6.9, U9.20 (IO12)
unnamed: D3.2 (A), U8.7 (~CHRG)
unnamed: D3.1 (K), R13.1
unnamed: D4.2 (A), U8.6 (~STDBY)
unnamed: D4.1 (K), R14.1
unnamed: J5.A5 (CC1), R12.1
unnamed: J5.B5 (CC2), R11.1
unnamed: Q2.2 (D), Q2.5 (D)
unnamed: R15.2, U8.2 (PROG)
unnamed: R16.2, U8.1 (TEMP)
unnamed: C21.1, U10.1 (CTG)
unnamed: C22.2, U10.3 (VDD)
OC: Q2.4 (G), U6.3 (OC)
OD: Q2.6 (G), U6.1 (OD)
TP_INT: J6.2, U9.15 (IO3)
TP_RST: J6.1, U9.4 (IO4)
VBUS: C15.1, J5.A4 (VBUS), J5.A9 (VBUS), J5.B4 (VBUS), J5.B9 (VBUS), R13.2, R14.2, U8.4 (V_{CC}), U8.8 (CE)

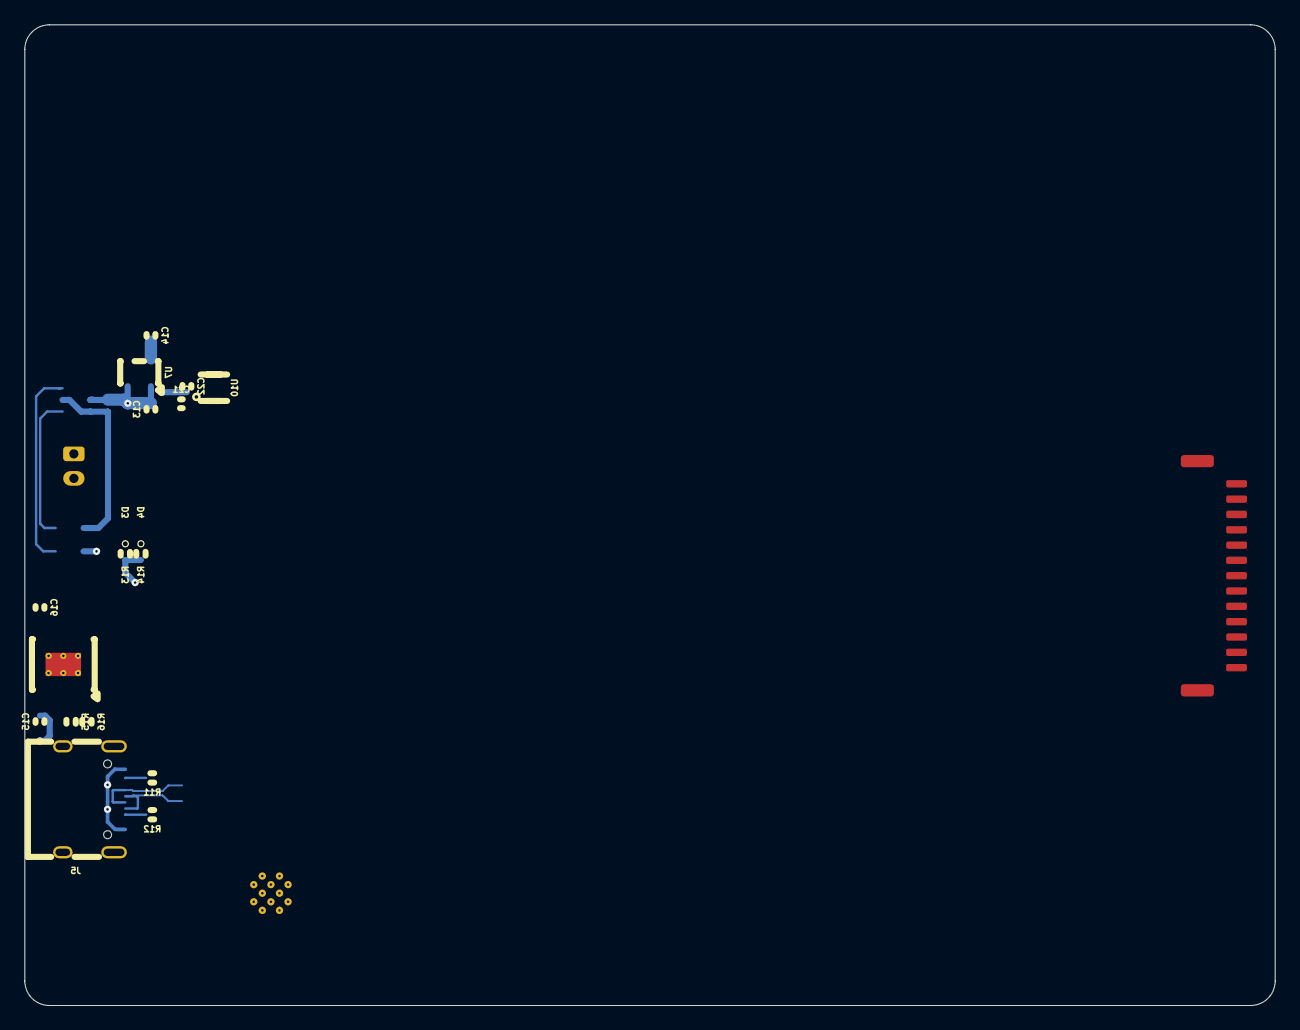
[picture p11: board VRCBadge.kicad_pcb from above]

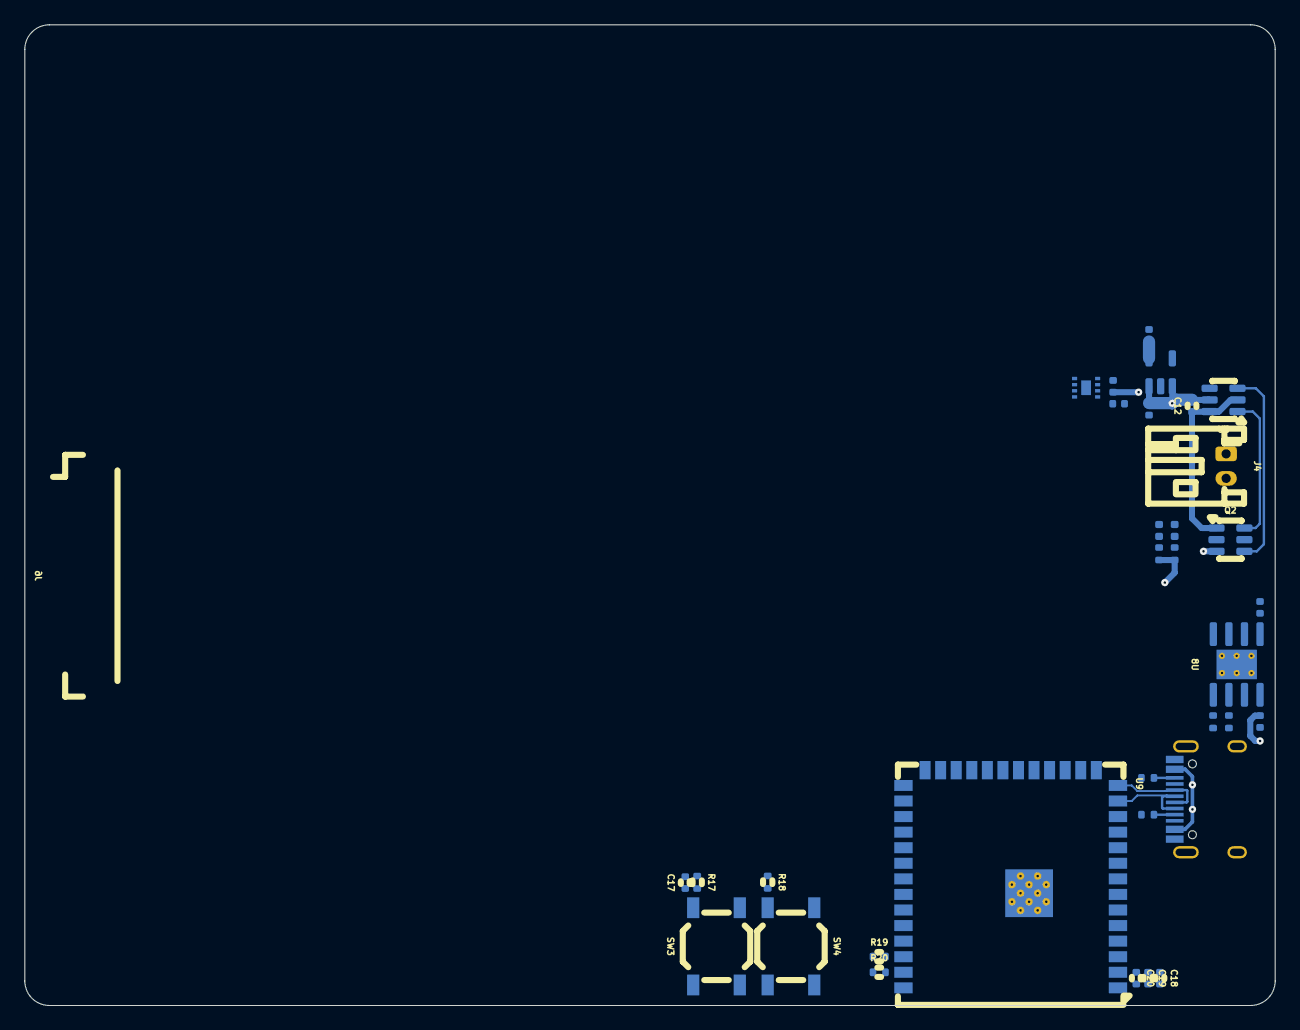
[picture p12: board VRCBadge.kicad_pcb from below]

Board: 4 copper layers, 102.0 x 80.0 mm, 34 parts (33 on the bottom side), 34 nets.

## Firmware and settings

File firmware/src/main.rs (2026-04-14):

mod callbacks;
mod display;
mod dns;
mod event_loop;
mod logger;
mod pending;
mod platform;
mod profile;
mod storage;
mod sysinfo;
mod touch;
mod ui_helpers;
mod web;
mod wifi;
mod wifi_state;

use std::cell::RefCell;
use std::sync::{Arc, Mutex};
use std::time::Instant;

use esp_idf_hal::ledc::{config::TimerConfig, LedcDriver, LedcTimerDriver};
use esp_idf_hal::peripherals::Peripherals;
use esp_idf_hal::units::FromValueType;
use esp_idf_svc::eventloop::EspSystemEventLoop;
use esp_idf_svc::nvs::EspDefaultNvsPartition;
use esp_idf_svc::wifi::{BlockingWifi, EspWifi};
use esp_idf_sys as _;
use slint::{Image, Rgb8Pixel, SharedPixelBuffer};

use crate::platform::Esp32Platform;
use crate::touch::TouchController;
use crate::event_loop::LoopDeps;
use crate::pending::PendingState;
use crate::ui_helpers::{apply_profile_colors, apply_rounded_corners};
use crate::wifi_state::WiFiState;

// Generated by slint-build from ui/badge.slint
slint::include_modules!();

fn main() -> anyhow::Result<()> {
    // Initialize dual logger (serial + ring buffer for About page)
    logger::init();
    let boot_time = Instant::now();
    log::info!("VRCBadge firmware starting");

    // Take hardware peripherals
    let peripherals = Peripherals::take()?;

    // --- Persistent storage (NVS + SPIFFS) ---
    let nvs_partition = EspDefaultNvsPartition::take()?;
    let nvs_for_storage = nvs_partition.clone(); // clone before WiFi consumes it
    let nvs = std::rc::Rc::new(RefCell::new(storage::init_nvs(nvs_for_storage)?));
    storage::init_spiffs()?;

    // --- WiFi AP + HTTP server ---
    let sys_loop = EspSystemEventLoop::take()?;
    let (wifi_driver, ap_ip) = wifi::init(peripherals.modem, sys_loop, nvs_partition)?;
    let wifi_handle: Arc<Mutex<BlockingWifi<EspWifi<'static>>>> = Arc::new(Mutex::new(wifi_driver));
    dns::start(ap_ip)?;
    let saved_profile = storage::load_profile(&nvs.borrow()).unwrap_or_default();
    let pending = PendingState::new(saved_profile.clone());
    let _server = web::init(
        ap_ip,
        pending.background.clone(),
        pending.avatar.clone(),
        pending.current_profile.clone(),
        pending.profile.clone(),
    )?;

    // --- Slint platform ---
    let esp_platform = Esp32Platform::new();
    let window = esp_platform.window();
    slint::platform::set_platform(Box::new(esp_platform))
        .map_err(|e| anyhow::anyhow!("Failed to set Slint platform: {:?}", e))?;

    // --- Display (ST7262 RGB parallel panel) ---
    // The RGB panel driver allocates a framebuffer in PSRAM and continuously
    // DMA-refreshes the display. No SPI, no manual pixel pushing.
    let (_display, framebuffer) = display::init()?;

    // --- Backlight PWM (600Hz, 8-bit, GPIO 2) ---
    // The JC8048W550 backlight is driven through a boost LED driver IC (U5).
    // GPIO 2 connects to the IC's EN pin, which accepts PWM for dimming.
    // 600Hz matches the Arduino demos for this board.
    let timer = LedcTimerDriver::new(
        peripherals.ledc.timer0,
        &TimerConfig::new()
            .frequency(600.Hz().into())
            .resolution(esp_idf_hal::ledc::Resolution::Bits8),
    )?;
    let mut backlight = LedcDriver::new(peripherals.ledc.channel0, timer, peripherals.pins.gpio2)?;
    let max_duty = backlight.get_max_duty();
    backlight.set_duty(max_duty / 2)?; // Start at 50% brightness
    log::info!("Backlight PWM initialized (GPIO 2, 600Hz, 50%)");

    // --- Touch (GT911 over I2C) ---
    let touch = match TouchController::new(
        peripherals.i2c0,
        peripherals.pins.gpio19.into(), // SDA
        peripherals.pins.gpio20.into(), // SCL
        peripherals.pins.gpio38.into(), // Touch RST
    ) {
        Ok(t) => Some(t),
        Err(e) => {
            log::warn!("Touch init failed (display/WiFi still active): {e}");
            None
        }
    };

    // --- Create UI ---
    let ui = BadgeUI::new().map_err(|e| anyhow::anyhow!("Failed to create UI: {:?}", e))?;

    // Set initial values from saved (or default) profile
    apply_profile_colors(&ui, &saved_profile);
    ui.set_display_name(saved_profile.display_name.into());
    ui.set_tagline(saved_profile.tagline.into());
    ui.set_twitter_handle(saved_profile.twitter_handle.into());
    ui.set_discord_handle(saved_profile.discord_handle.into());
    ui.set_battery_percent(100);
    ui.set_wifi_ip(ap_ip.to_string().into());
    ui.set_firmware_version(sysinfo::firmware_version().into());

    // Restore saved avatar from SPIFFS (216 KB @ 240x300)
    if let Some(mut rgb_data) = storage::load_image("avatar", storage::AVATAR_IMAGE_SIZE) {
        apply_rounded_corners(
            &mut rgb_data,
            storage::AVATAR_WIDTH,
            storage::AVATAR_HEIGHT,
            20,
            [0x2a, 0x2a, 0x4a],
        );
        let buffer = SharedPixelBuffer::<Rgb8Pixel>::clone_from_slice(
            &rgb_data,
            storage::AVATAR_WIDTH,
            storage::AVATAR_HEIGHT,
        );
        ui.set_avatar_image(Image::from_rgb8(buffer));
    }

    // Restore saved background from SPIFFS
    if let Some(rgb_data) = storage::load_image("background", storage::BACKGROUND_IMAGE_SIZE) {
        let buffer = SharedPixelBuffer::<Rgb8Pixel>::clone_from_slice(
            &rgb_data,
            platform::DISPLAY_WIDTH,
            platform::DISPLAY_HEIGHT,
        );
        ui.set_background_image(Image::from_rgb8(buffer));
    }

    // Flag to dismiss virtual keyboard from the main loop (dispatch_event
    // doesn't reliably defocus TextInput when called from inside a callback).
    // Set to true by `WiFiState::poll` on a successful connect; consumed by
    // the event loop on the next tick.
    let dismiss_keyboard = std::sync::Arc::new(std::sync::atomic::AtomicBool::new(false));

    // --- Auto-connect to saved WiFi network ---
    // Try to connect at boot if credentials are saved. On failure, continue
    // with AP-only mode and show a dimmed WiFi icon. Runs synchronously
    // before any UI callbacks are wired so that nothing else can grab the
    // wifi handle while we're holding it.
    let mut sta_connected = false;
    if let Some((ssid, password)) = storage::load_wifi_credentials(&nvs.borrow()) {
        log::info!("Auto-connecting to saved WiFi: {ssid}");
        if let Ok(mut wifi) = wifi_handle.lock() {
            match wifi::connect_sta(&mut wifi, &ssid, &password) {
                Ok(ip) => {
                    ui.set_sta_connected(true);
                    ui.set_sta_ssid(ssid.into());
                    ui.set_sta_ip(ip.to_string().into());
                    sta_connected = true;
                }
                Err(e) => {
                    log::warn!("Auto-connect failed: {e}");
                    ui.set_sta_connected(false);
                    ui.set_toast_message("WiFi connection failed".into());
                    ui.set_toast_visible(true);
                }
            }
        }
    }
    // Track whether we have saved credentials (for dimmed icon vs hidden)
    let has_wifi_credentials = storage::load_wifi_credentials(&nvs.borrow()).is_some();
    ui.set_has_wifi_credentials(has_wifi_credentials || sta_connected);

    // --- Wire all UI callbacks (brightness, virtual keyboard, WiFi) ---
    // Wired AFTER auto-connect so the synchronous boot connect can't race
    // with a user-initiated scan/connect from a stale-rendered UI.
    let wifi_state = WiFiState::new();
    callbacks::wire(
        &ui,
        wifi_handle.clone(),
        wifi_state.clone(),
        nvs.clone(),
        backlight,
        max_duty,
    );

    log::info!("Boot complete, entering main loop");

    event_loop::run(LoopDeps {
        window,
        framebuffer,
        ui,
        touch,
        nvs,
        wifi_handle,
        wifi_state,
        pending,
        dismiss_keyboard,
        sta_connected,
        boot_time,
    });
}

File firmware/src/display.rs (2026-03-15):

//! Display driver for the JC8048W550C — ST7262 RGB parallel panel.
//!
//! The ST7262 uses the ESP32-S3's built-in LCD_CAM peripheral in 16-bit RGB565
//! parallel mode. The hardware continuously DMA-refreshes the display from a
//! framebuffer in PSRAM at the pixel clock rate (~21MHz, ~51 FPS).
//!
//! Unlike SPI displays, there are no commands to send — we just write pixels
//! to the framebuffer and the hardware handles the rest.
//!
//! **Bounce buffers**: The framebuffer lives in PSRAM, but DMA reads from two
//! internal SRAM bounce buffers instead of PSRAM directly. An ISR copies data
//! from PSRAM to the bounce buffers, avoiding EDMA bandwidth contention with
//! the CPU, I2C, WiFi, and flash operations that share the PSRAM bus. Without
//! bounce buffers, the display drifts/shifts when any of these compete for
//! PSRAM bandwidth.
//!
//! The `esp_lcd_rgb_panel` API is not exposed by `esp-idf-sys` bindgen,
//! so we declare the FFI manually. The C implementation is linked via
//! `esp_lcd_panel_rgb.c.obj` in the ESP-IDF build.

use slint::platform::software_renderer::Rgb565Pixel;

use crate::platform::{DISPLAY_HEIGHT, DISPLAY_WIDTH};

// ---------------------------------------------------------------------------
// Raw FFI declarations for esp_lcd_rgb_panel (esp_lcd_panel_rgb.h)
// ---------------------------------------------------------------------------

/// `lcd_clock_source_t` = `SOC_MOD_CLK_PLL_F160M` = 6 in ESP-IDF v5.3
/// (soc_module_clk_t enum starts at 1: CPU=1, RTC_FAST=2, RTC_SLOW=3, APB=4, PLL_F80M=5, PLL_F160M=6)
type LcdClockSourceT = i32;
const LCD_CLK_SRC_PLL160M: LcdClockSourceT = 6;

/// Mirror of `esp_lcd_rgb_timing_t` from esp_lcd_panel_rgb.h
#[repr(C)]
#[derive(Debug, Default)]
struct EspLcdRgbTimingT {
    pclk_hz: u32,
    h_res: u32,
    v_res: u32,
    hsync_pulse_width: u32,
    hsync_back_porch: u32,
    hsync_front_porch: u32,
    vsync_pulse_width: u32,
    vsync_back_porch: u32,
    vsync_front_porch: u32,
    /// Bitfield flags: hsync_idle_low:1, vsync_idle_low:1, de_idle_high:1,
    ///                  pclk_active_neg:1, pclk_idle_high:1
    flags: u32,
}

/// Mirror of `esp_lcd_rgb_panel_config_t` from esp_lcd_panel_rgb.h.
///
/// Uses `SOC_LCD_RGB_DATA_WIDTH = 16` for the data_gpio_nums array.
#[repr(C)]
struct EspLcdRgbPanelConfigT {
    clk_src: LcdClockSourceT,
    timings: EspLcdRgbTimingT,
    data_width: usize,
    bits_per_pixel: usize,
    num_fbs: usize,
    bounce_buffer_size_px: usize,
    sram_trans_align: usize, // deprecated but must be present for struct layout
    psram_trans_align: usize, // union with dma_burst_size
    hsync_gpio_num: i32,
    vsync_gpio_num: i32,
    de_gpio_num: i32,
    pclk_gpio_num: i32,
    disp_gpio_num: i32,
    data_gpio_nums: [i32; 16], // SOC_LCD_RGB_DATA_WIDTH = 16
    /// Bitfield flags: disp_active_low:1, refresh_on_demand:1, fb_in_psram:1,
    ///                  double_fb:1, no_fb:1, bb_invalidate_cache:1
    flags: u32,
}

extern "C" {
    fn esp_lcd_new_rgb_panel(
        rgb_panel_config: *const EspLcdRgbPanelConfigT,
        ret_panel: *mut esp_idf_sys::esp_lcd_panel_handle_t,
    ) -> esp_idf_sys::esp_err_t;

    fn esp_lcd_rgb_panel_get_frame_buffer(
        panel: esp_idf_sys::esp_lcd_panel_handle_t,
        fb_num: u32,
        fb0: *mut *mut core::ffi::c_void,
        ...
    ) -> esp_idf_sys::esp_err_t;
}

// ---------------------------------------------------------------------------
// Pin assignments (fixed on JC8048W550 board)
// ---------------------------------------------------------------------------

/// Data Enable
const PIN_DE: i32 = 40;
/// Vertical Sync
const PIN_VSYNC: i32 = 41;
/// Horizontal Sync
const PIN_HSYNC: i32 = 39;
/// Pixel Clock
const PIN_PCLK: i32 = 42;

/// 16-bit RGB565 data bus — order: B[0:4], G[0:5], R[0:4]
/// This matches the ESP-IDF `data_gpio_nums` array layout for little-endian RGB565.
const DATA_PINS: [i32; 16] = [
    8, 3, 46, 9, 1, // B0..B4
    5, 6, 7, 15, 16, 4, // G0..G5
    45, 48, 47, 21, 14, // R0..R4
];

// ---------------------------------------------------------------------------
// Timing parameters (from vendor Arduino demos)
// ---------------------------------------------------------------------------

/// Pixel clock frequency in Hz.
/// 21MHz gives ~51 FPS with the standard porch values.
/// The ST7262 panel supports up to ~25MHz; 21MHz is a safe sweet spot.
const PIXEL_CLOCK_HZ: u32 = 21_000_000;

/// Horizontal/Vertical sync timing (symmetric 8/4/8 for this panel).
const H_FRONT_PORCH: u32 = 8;
const H_PULSE_WIDTH: u32 = 4;
const H_BACK_PORCH: u32 = 8;
const V_FRONT_PORCH: u32 = 8;
const V_PULSE_WIDTH: u32 = 4;
const V_BACK_PORCH: u32 = 8;

/// Total number of pixels in the framebuffer (800 x 480).
const FRAMEBUFFER_PIXELS: usize = DISPLAY_WIDTH as usize * DISPLAY_HEIGHT as usize;

/// Opaque handle to the ESP-IDF RGB panel.
/// We keep this alive so the DMA refresh continues.
pub struct RgbDisplay {
    _panel: esp_idf_sys::esp_lcd_panel_handle_t,
}
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

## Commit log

2026-01-27 docs: migrate hardware platform from CM4 to Pi Zero 2W with custom PCB
    Replace Raspberry Pi CM4 + carrier board + acrylic enclosure design
    with Pi Zero 2W + custom EasyEDA PCB + LiPo pouch cell. Updates all
    hardware docs, software architecture, and development roadmap to
    reflect the new platform. Adds PCB design guide with schematic blocks
    and fabrication notes.
2026-01-27 docs: add PCB design guideline and finalize component choices
    Add step-by-step PCB design walkthrough for EasyEDA Pro covering
    schematic blocks, layout, JLCPCB ordering, and hand-soldering.
    Finalize component selection: TPS61023 boost, MAX17048 fuel gauge,
    TPS22918 load switch with LCSC part numbers.
2026-01-28 docs: raspberryPi Z2W to esp32
2026-02-09 docs: remove Pi references, update to ESP32-S3 with Waveshare 3.5" RPi LCD (F)
2026-02-09 feat: add ESP32-S3 firmware scaffold with Slint UI
    [partitions.csv]
2026-02-09 feat: add badge assets with Phosphor battery icons
2026-02-10 fix: add rust-toolchain.toml and prevent usize underflow in display renderer
    [display.rs]
2026-02-10 feat: add display brightness control with PWM backlight and settings slider
2026-02-10 feat: add background image upload via HTTP with browser-side resize
    Add web upload page at GET / that allows users to select an image,
    resize it to 480x320 in the browser, strip alpha to raw RGB888, and
    POST it to /api/background. The main loop polls for pending image
    data and updates the Slint UI background via SharedPixelBuffer.
    Note: requires PSRAM for the 450KB image buffer (ESP32-S3 only).
2026-02-11 fix: backport display, touch, and build fixes from esp32-port
    - Display: add ColorInversion::Inverted and flip_vertical() for correct
    colors and non-mirrored output on Waveshare ST7796S panel
    - Touch: proper GT911 reset sequence with INT pin driven LOW for I2C
    address selection, then reconfigured as input with pull-down
    - Touch: coordinate transform from portrait GT911 to landscape display
    - Touch: track last_position for PointerReleased (fixes click detection)
    - Touch: add debug logging for poll stats and per-touch coordinates
    - Brightness: debounce PWM updates with 2% threshold to reduce flicker
    - Build: add scale_factor(1.0) and SDF fonts to reduce binary size
    - Assets: switch from SV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
    [display.rs, main.rs, touch.rs]
2026-02-13 feat: add captive portal, fix display/touch, and optimize SPI for ESP32-S3
    [display.rs, main.rs, touch.rs]
2026-02-13 perf: full framebuffer rendering with DMA dirty-rect updates
2026-02-13 fix: switch from SDF to bitmap fonts to fix missing spaces in text
2026-02-26 docs: WaveShare 3.5 Spi LCD (F)
2026-02-26 feat: KiCad project init
    [VRCBadge.kicad_pcb, VRCBadge.kicad_sch]
2026-02-26 feat: mcu schematic
    [mcu.kicad_sch]
2026-02-27 chore: add KiCad-specific entries to .gitignore
2026-02-27 feat: add power, peripheral schematics and custom component libraries
    [VRCBadge.kicad_sch, mcu.kicad_sch, peripheral.kicad_sch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]
2026-02-27 docs: PCB layout board specification and component placement
2026-02-27 docs: add schematic image and hardware description to README
2026-02-28 docs: update hardware overview to match current schematic
2026-03-01 docs: add PCB layout link to index and clarify unused MISO pin
2026-03-02 fix: rewire MAX17048 CELL pin from +3V3 to +BATT
    [peripheral.kicad_sch]
2026-03-02 feat: assign footprints and add no_connect flags for PCB readiness
    - Assign footprints to 28 root-sheet components (0603 passives,
    0805 for 10uF, TL3342 switches, HRO USB-C, JST-PH/GH connectors)
    - Add no_connect flags to MAX17048 ALRT and QSTRT pins
    - Rewire MAX17048 CELL pin from +3V3 to +BATT on root sheet
    [VRCBadge.kicad_sch]
2026-03-02 refactor: flatten schematic to single root sheet and fix ERC violations
    - Remove hierarchical sub-sheets (power, mcu, peripheral) that
    duplicated root-sheet components and caused ERC conflicts
    - Fix MAX17048 symbol pin types from unspecified to correct
    electrical types (power_in, bidirectional, input, passive, etc.)
    - Sync DW01A lib_symbol with KiCad Battery_Management library
    [VRCBadge.kicad_sch]
2026-03-02 docs: add display module mechanical dimensions from specsheet
    Extract measurements from Waveshare 3.5" RPi LCD (F) specsheet:
    panel 92.44x61.00mm, active area 73.84x49.36mm, stack height
    14.60mm, back PCB 56.00mm wide. Update component references to
    match flattened root sheet.
2026-03-02 feat: import netlist into PCB layout
    [VRCBadge.kicad_pcb]
2026-03-02 feat: add board outline and initial component placement
    [VRCBadge.kicad_pcb]
2026-03-03 chore: change usb data line global label and update footprint to 0402_1005
    [VRCBadge.kicad_sch]
2026-03-04 chore: add track width rules
2026-03-05 wip: pcb
    [VRCBadge.kicad_pcb]
2026-03-06 feat: fusion 360 init
    [enclosure.f3d]
2026-03-07 feat: update enclosure drawing
    [enclosure.f3d]
2026-03-07 feat: assembly init
2026-03-07 chore: enclosure images
2026-03-07 docs: update enclosure images
2026-03-12 feat: port firmware to JC8048W550C dev board (800x480 RGB parallel display)
    Replace SPI/mipidsi display driver with ESP-IDF RGB parallel panel via raw FFI
    for the ST7262-based JC8048W550C board. Key changes:
    - display.rs: DMA-driven RGB565 framebuffer in PSRAM with bounce buffers
    - main.rs: GPIO 2 backlight (600Hz PWM), new touch pins (19/20/38)
    - touch.rs: simplified GT911 polling, direct coordinate mapping
    - badge.slint: redesigned UI for 800x480 with PageHeader component
    - sdkconfig: SPIRAM XIP configs for stable bounce buffer operation
    - Removed mipidsi, embedded-graphics-core, embedded-hal dependencies
    [display.rs, main.rs, touch.rs]
2026-03-12 feat: add rounded corners to avatar image via Rust-side pixel processing
    Slint's software renderer does not support border-radius clipping
    (upstream #4176). Work around this by painting corner pixels outside
    the rounded rect with the container background color in Rust before
    passing the image to Slint.
    - Add apply_rounded_corners() helper with circle-based corner test
    - Apply rounding on both SPIFFS load and HTTP upload paths
    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
2026-03-12 feat: add virtual keyboard and WiFi icon assets
    Add on-screen QWERTY keyboard for touchscreen text input (WiFi
    password entry). Simplified from the official Slint virtual_keyboard
    example using Unicode glyphs for special keys instead of SVG assets.
    - New ui/virtual_keyboard.slint with letters + numbers/symbols layouts
    - Keyboard overlays bottom 192px, visibility bound to TextInputInterface
    - Key dispatch wired in main.rs via VirtualKeyboardHandler callback
    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
2026-03-12 feat: add WiFi station mode backend and badge WiFi indicator
    Rewrite wifi.rs to support AP+STA mixed mode via Configuration::Mixed.
    Add scan(), connect_sta(), disconnect_sta(), sta_status() functions.
    On connect failure, automatically revert to AP-only mode.
    - storage.rs: add NVS save/load/delete for WiFi credentials (SSID+password)
    - main.rs: auto-connect to saved network on boot (10s timeout),
    poll STA status every ~2s, shared wifi handle via Arc<Mutex<>>
    - badge.slint: add WiFi indicator icon next to battery on badge page
    (green wifi-high when connected, dimmed wifi-x when disconnected)
    [main.rs, storage.rs]
2026-03-12 feat: add WiFi connect page UI, toast notifications, and wire all callbacks
    Complete Stage 3 of WiFi station mode implementation:
    - WiFi connect page (page 5): scan for networks, select AP, enter
    password, connect/disconnect/forget buttons
    - WiFi page expanded with AP section, Station section showing
    connection status, and 'Connect to Network' navigation
    - Toast notification overlay with 5-second auto-hide for boot
    connection failures
    - NVS handle wrapped in Rc<RefCell<>> for shared access across
    Slint callbacks
    - Auto-connect to saved WiFi credentials at boot
    - STA status polling in main loop (~every 2 seconds)
    - Password TextInput uses visibility toggle instead of conditional
    to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
    [main.rs]
2026-03-15 fix: WiFi scan requires STA interface, temporarily switch to mixed mode
    WiFi scan was hanging because esp_wifi_scan_start requires the STA
    interface to be active. In AP-only mode, the scan blocks indefinitely
    since no STA interface exists.
    Fix: detect AP-only configuration before scanning, temporarily switch
    to Mixed mode (AP+STA with dummy STA config), perform the scan, then
    revert to AP-only. If already in Mixed mode (STA connected), scan
    runs directly without mode switching.
2026-03-15 perf: increase pixel clock to 21MHz, reduce poll interval, increase stack
    - Pixel clock 16MHz -> 21MHz (~39 -> ~51 FPS panel refresh rate)
    - Main loop sleep cap 16ms -> 8ms (faster touch response and rendering)
    - Main task stack 32KB -> 64KB (required for WiFi UI + Slint rendering)
    - Remove unused flush_dirty_region() (no-op since bounce buffers
    handle cache coherency; render result is no longer captured)
    [display.rs, main.rs]
2026-03-15 docs: add OTA firmware update design document
    Two-stage plan for OTA updates via GitHub releases:
    - Stage 1: partition table redesign (factory -> ota_0/ota_1) + ota.rs module
    - Stage 2: About page UI + auto-check on STA connect
    Includes architecture flowchart, sequence diagram, and partition
    layout diagrams in Mermaid.
2026-03-22 fix: improve WiFi connect page UX and move operations to background
    UI layout fixes:
    - Hide scan results list when virtual keyboard is open so password
    field and action buttons remain visible above the keyboard
    - Add overflow: elide to status text, STA info, and selected SSID
    to prevent long strings from breaking the layout
    - Add empty state text when scan results are empty
    - TextInput handles Escape key via clear-focus() for reliable
    keyboard dismissal
    Button and state management:
    - Connect button disabled while scanning or when password is empty
    for secured networks
    - Disconnect/Forget buttons only shown when the selected AP matches
    the currently connected SSID
    - Clear selection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
    [main.rs]
2026-04-14 refactor: split main.rs into focused modules (582 → 213 lines)
    main.rs had grown into a god file mixing peripheral init, four WiFi
    callback closures, a polling state machine for async WiFi ops, three
    parallel mutex slots for web uploads, and the entire event loop in one
    480-line main() function. Extract each concern into its own module so
    main.rs reads top-to-bottom as a linear boot script.
    New modules:
    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
2026-04-14 docs: add working prototype photo and enclosure WIP image to README
    Replace Slint preview screenshot with a real photo of the badge UI
    running on a Guition JC8048W550 dev board, and add a real photo of
    the work-in-progress enclosure alongside the Fusion 360 renders.
